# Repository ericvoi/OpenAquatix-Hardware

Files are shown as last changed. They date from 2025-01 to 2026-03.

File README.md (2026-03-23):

# License



# OpenAquatix Hardware
PCB files for the open-source underwater acoustic modem: OpenAquatix.

OpenAquatix is an open-source underwater acoustic modem that provides a flexible and performative interface for research applications and small-scale hobby projects. Key hardware features include:

1. USB 2.0 interface at 480Mbps
2. In-built power consumption monitoring
3. Ambient pressure and temperature sensing
4. Low-noise analog front-end
5. 6th order bandpass filter on input signals
6. Primary processor is an STM32H723 (512 kB flash and RAM) running at 480 MHz for onboard processing of messages
7. Output power of 30W continuous, 60W peak.
8. Reverse polarity and surge protection
9. Standby power consumption of 2 mW
10. Listening power consumption of 100 mW
11. Active processing power consumption of 1 W
12. Fully customizable daughter card for limitless AUV/User - Modem communication protocols (Ethernet, RS232, RS485, CAN, Modbus, etc.)
13. Cost of each board (transducer excluded) fully assembled at quantities of 5+: $110 USD
14. Input feedback network to test novel modulation/demodulation techniques on real hardware
15. Output feedback network to calibrate phase non-linearities in the output chain
16. 2 MB external flash
17. SWD debugging interface

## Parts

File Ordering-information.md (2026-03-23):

_The information in this guide applies to board version(s) v2 only_

# Ordering Boards From JLCPCB

 The production info for these boards has only been generated for JLCPCB. Using another manufacturer will require you to generate their required production information.

## Option 1: Ordering Assembled Boards from JLCPCB

1. Create an account on <https://jlcpcb.com> if you do not have one already
1. Go to <https://jlcpcb.com/parts> and upload the bom file found in `v2/src/production/OpenAquatix_v2_bom.csv` to the Bom tool. 
2. Select the quantity required and click "Process BOM"
3. Verify that the matched part count aligns with the expected value (129 for v2 TODO CHANGE ME) for the board. In case of discrepancies, please open an issue
4. Click on "Add All to My parts lib"
5. Go to <https://jlcpcb.com/user-center/smtPrivateLibrary/partsCart> and verify that the number of parts in the cart aligns with the number ordered in previous steps. In case of any discrepancies, first try to scroll down in the cart, but if only 100 parts get loaded, try switching browsers. Edge and Chrome have been observed to only load 100 parts in the cart while there have been no issues with Firefox. Once confirmed, checkout.
6. Some of the parts ordered in the previous step are "pre-ordered" meaning that they are not currently in-stock, but JLCPCB will attempt to source them from their suppliers. Typical lead times for these components are ~5-15 business days. If they cannot source a component, then they will notify you and you can either source the component from another supplier (Digikey, Mouser, etc.) and solder it yourself or send them the component (consign it). The latter option is not recommended as there are egregious shipping fees and delays. You can also try to substitute the component. JLCPCB will give you a quote ~2 days after the order is placed where you can either decide that the quoted price/shipping time is adequate or that it is too long and cancel the item.
7. Once all of the items have arrived in the JLCPCB parts library, you can begin the actual order for the assembled boards by uploading`v2/src/production/OpenAquatix_v2.zip` to <https://cart.jlcpcb.com/quote>.
8. Update the PCB order specifications as follows:
    1. `PCB Qty` -> The minimum multiple of 5 greater than the number of boards you need. E.g. 6 boards -> qty: 10.
    1. `Material Type` -> `FR4 TG155`
    2. `Specify Stackup` -> `Yes` and change `No Requirement` to `JLC06161H-3313`
9. Select `PCB Assembly` at the bottom of the page and change the following options:
    1. `PCBA Type` -> `Standard`
    2. `PCBA Qty` -> The number of boards you want to order
    3. (Optional) `Confirm Parts Placement` -> `Yes`. For advanced users only who could reasonably be able to detect any flaws with production files (unlikely but recommended for larger orders)
    4. `Bake Components` -> `Yes` and request that C2843785 is baked. This is the WS2812B LED
    5. (Optional, adds 1 day, but is cheap) `Depanel boards & edge rail before delivery` -> `Yes`
10. Click on `Next` on the right side column to get to the assembly details
11. Upload the BOM and positions files on the next screen
12. Place the board order

## Option 2: Assembling Boards Yourself

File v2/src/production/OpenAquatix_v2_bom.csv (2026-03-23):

Designator | Footprint | Quantity | Value | LCSC Part #
C1, C10, C104, C106, C107, C108, C11, C110, C112, C113, C114, C115, C116, C117, C128, C129, C130, C131, C133, C134, C14, C140, C141, C143, C144, C145, C146, C147, C18, C19, C29, C38, C4, C40, C41, C42, C53, C54, C57, C58, C6, C61, C65, C68, C7, C71, C77, C79, C8, C80, C9, C91 | 0603 | 52 | 100n | C14663
C100, C101 | 0603 | 2 | 1n,50V | C309468
C102, C103 | 0603 | 2 | 10n,50V | C57112
C105, C142, C2, C20, C24, C33, C63, C81, C85, C86, C87 | 0603 | 11 | 1u | C15849
C109, C132, C135, C136, C137, C138, C139, C36, C69, C94, C95 | 0603 | 11 | 1n | C309468
C111 | 0603 | 1 | 10u | C2959727
C119, C89, C90, C92, C93 | 0603 | 5 | 33n | C576851
C12, C17 | 0603 | 2 | 8p | C36508
C120, C43 | 0805 | 2 | 10u | C15850
C121, C30, C83 | 0603 | 3 | 10n | C57112
C122, C3, C5, C66, C67 | 0603 | 5 | 2u2 | C23630
C123 | 2220 | 1 | 68n,200V,5%,C0G/NP0 | C2175506
C13, C16 | 0603 | 2 | 47p | C1671
C15, C39 | 0603 | 2 | 4u7 | C19666
C21, C22, C26 | 1210 | 3 | 10u,50V | C77102
C23 | 0603 | 1 | 330n | C1615
C25, C31, C32 | 0805 | 3 | 2u2 | C377773
C27, C55, C56 | 1210 | 3 | 4u7,50V | C86052
C28 | 0603 | 1 | 68p | C62782
C34 | 1210 | 1 | 47u | C77101
C35, C37, C44 | 1210 | 3 | 22u | C309062
C45, C46, C47 | 1210 | 3 | 10u,63V | C437568
C48, C50, C51, C52 | 0805 | 4 | 22u | C45783
C49 | 0805 | 1 | 1u,100V | C105952
C59, C60 | 1210 | 2 | 22u,25V | C309062
C62, C64 | 0603 | 2 | 30p | C1658
C70 | 0603 | 1 | 1n2 | C576796
C72 | 0603 | 1 | 100p | C14858
C73 | 0603 | 1 | 6n8 | C1631
C74, C76, C82, C84 | 0805 | 4 | 1u | C105952
C75 | 1210 | 1 | 10u | C77102
C96, C97 | 1206 | 2 | 680n,100V | C710483
C98, C99 | 0805 | 2 | 220n,100V | C513710
D1 | LED_WS2812B_PLCC4_5.0x5.0mm_P3.2mm | 1 | WS2812B | C2843785
D10 | SC-59 | 1 | 1SS396,LF | C2762668
D11 | D_SOD-323F | 1 | BAT54WS | C22629
D2 | TO-277B | 1 | PDS760-13 | C3018534
D3 | SMBJ | 1 | SMBJ24CA | C83268
D4 | SOD-123_ONS | 1 | MMSZ12T1G | C72599
D5, D6, D7, D8 | 0603 | 4 | Red | C2286
D9 | D_SMC | 1 | SMLJ150CA | C5924268
F1 | 1206 | 1 | 6A | C3165603
J1 | PinHeader_2x05_P1.27mm_Vertical | 1 | Conn_ARM_JTAG_SWD_10 | C5883263
J2, J3 | USB_Micro-B_Amphenol_10118193-0001LF_Horizontal | 2 | USB_B_Micro | C132562
J4 | UAM_DaughterCard | 1 | ~
J5 | CONN2_2601-1102_WAG | 1 | 2601-1102 | C7509568
J6 | CONN3_2601-1103_WAG | 1 | 2601-1103 | C7472698
L1 | L_Bourns_SRP6060FA | 1 | 6u8 | C2047089
L2 | L_Bourns_SRP6060FA | 1 | 15u | C2047415
L3 | L_Bourns-SRN8040_8x8.15mm | 1 | 33u | C780189
L4, L5 | CDRH127L125NP | 2 | 33u | C2595984
L6 | B82477D4xxxM900 | 1 | 136u | C1016922
L7, L9 | L_Pulse_PA4344 | 2 | 100u | C2452965
Q1, Q10, Q12, Q13, Q4, Q5, Q6, Q7, Q8, Q9 | SOT-23 | 10 | BSS138 | C40912
Q11 | SOT-23 | 1 | DMP3068L-7 | C151010
Q2 | VSON-8_3.3x3.3mm_P0.65mm_NexFET | 1 | CSD18543Q3A | C840100
Q3 | Vishay_PowerPAK_1212-8_Single | 1 | Si7617DN | C727607
R10, R11, R36, R85 | 0603 | 4 | 2k49 | C100897
R100, R13 | 0603 | 2 | 56k | C23206
R101 | 0603 | 1 | 8k66 | C23114
R102 | 0603 | 1 | 2k05 | C22900
R103 | 0603 | 1 | 16k9 | C25954
R104, R110, R111, R112, R29, R37, R56, R57, R6, R96 | 0603 | 10 | 10k | C25804
R105 | 0603 | 1 | 1k91 | C22853
R106 | 0603 | 1 | 28k | C22989
R107 | 0603 | 1 | 6k19 | C25978
R108 | 0603 | 1 | 1k18 | C858885
R109 | 0603 | 1 | 17k4 | C22819
R113, R115, R116, R18, R20, R26, R50, R53, R70, R73, R76, R79, R83, R89, R92 | 0603 | 15 | 100k | C25803
R114, R14, R40, R41, R46, R47, R97 | 0603 | 7 | 390R | C23151
R12 | 0603 | 1 | 33k | C4216
R15, R19, R21, R71, R74, R84 | 0603 | 6 | 2k | C22975
R16, R17, R48, R7, R88, R9 | 0603 | 6 | 22R | C23345
R22, R23, R43 | 0603 | 3 | 4k7 | C23162
R24 | 0603 | 1 | 28k7 | C100933
R25, R8, R90, R91, R93, R99 | 0603 | 6 | 1k | C21190
R27 | 0603 | 1 | 150k | C22807
R28 | 0603 | 1 | 21k | C22956
R30 | 0603 | 1 | 267R | C22924
R31 | 0603 | 1 | 68k | C23231
R32 | 0603 | 1 | 39k | C23153
R33, R67, R68 | 0603 | 3 | 100R | C22775
R34, R66 | 0805 | 2 | 10m | C104574
R35 | 0603 | 1 | 71k5 | C23103
R38 | 0603 | 1 | 300k | C23024
R39, R62 | 0603 | 2 | 22k | C31850
R4 | 0603 | 1 | 47R | C23182
R42 | 0603 | 1 | 20k | C4184
R44, R49, R87 | 0603 | 3 | 1M | C22935
R45 | 0603 | 1 | 8k06 | C23112
R51, R54 | 0603 | 2 | 470R | C23179
R52 | 0603 | 1 | 499R | C23065
R55 | 0603 | 1 | 2k94 | C22909
R58 | 0603 | 1 | 806R | C23116
R59 | 0603 | 1 | 1k21 | C22835
R60, R61, R64, R65 | 0603 | 4 | 3R3 | C22979
R63 | 0603 | 1 | 30k,1% | C22984
R69, R72, R75, R78 | 0603 | 4 | 220R | C22962
R77, R80 | 0603 | 2 | 47k | C25819
R81 | 1206 | 1 | 160k,1% | C4437
R82 | 0603 | 1 | 1k6,1% | C22847
R86 | 0603 | 1 | 732R | C23106
R94 | 0603 | 1 | 200R | C8218
R95 | 0603 | 1 | 91k | C23265
R98 | 0603 | 1 | 86k6 | C23121
TP1, TP2 | TestPoint_Pad_D1.0mm | 2 | TestPoint
U1 | SOIC-8_5.3x5.3mm_P1.27mm | 1 | W25Q16JVSS | C82317
U10 | SOT-23-5 | 1 | TPS60403DBV | C11338
U11 | WSON-12-1EP_3x2mm_P0.5mm_EP1x2.65 | 1 | LM5155DSSR | C545416
U12 | SOT-23-5 | 1 | TPS72301DBV | C34678
U13, U14 | WSON-6-1EP_2x2mm_P0.65mm_EP1x1.6mm | 2 | TLV75733PDRVR | C2868428
U15 | SOT-23-6 | 1 | LMR54406 | C5219316
U16, U18, U4, U5 | USON-10_2.5x1.0mm_P0.5mm | 4 | TPD4E05U06DQA | C138714
U17 | QFN-24-1EP_4x4mm_P0.5mm_EP2.6x2.6mm | 1 | USB3343 | C112967
U19 | MSOP-10_3x3mm_P0.5mm | 1 | OPA2316 | C2060790
U2 | LQFP-100_14x14mm_P0.5mm | 1 | STM32H723VET6 | C730141
U20 | HTSSOP-44-1EP_6.1x14mm_P0.635mm_EP5.2x14mm_Mask4.31x8.26mm | 1 | TPA3244DDWR | C544669
U21 | ST_HLGA-10_2x2mm_P0.5mm_LayoutBorder3x2y | 1 | LPS22HH | C2827824
U22 | SOT-23-8 | 1 | INA219AIDCNR | C87469
U23, U25 | SOT-23-6 | 2 | OPA991SIDBVR | C2864547
U24, U3, U34 | SOT-363_SC-70-6 | 3 | TS5A4624 | C485533
U26 | SOT-23-5 | 1 | LM6211 | C2060609
U27, U28, U29, U30, U31, U32 | SOT-23-5 | 6 | LMV641MFX/NOPB | C2059681
U33 | TSSOP-10_3x3mm_P0.5mm | 1 | PGA113 | C2057394
U35 | RELAY_AQY_SO4_KS_PAN | 1 | AQY210S | C132163
U6, U7 | SOT-363_SC-70-6 | 2 | TPS22919 | C2149796
U8 | HTSOP-8-1EP_3.9x4.9mm_P1.27mm_EP2.4x3.2mm | 1 | BV1HB045EFJ-C | C17309972
U9 | LMR66430R5RXBR | 1 | LMQ66430R5RXBR | C22440565
Y1 | Crystal_SMD_3225-4Pin_3.2x2.5mm | 1 | 32.768 kHz | C213398
Y2 | Crystal_SMD_5032-4Pin_5.0x3.2mm | 1 | 8 MHz | C5154132
Y3 | Crystal_SMD_3225-4Pin_3.2x2.5mm | 1 | 26 MHz | C5143383

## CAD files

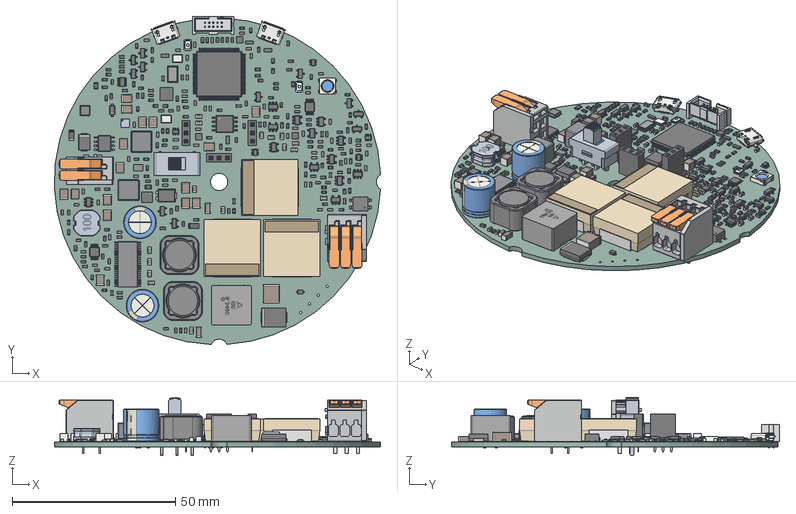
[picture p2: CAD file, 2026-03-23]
v2/src/3d_board/UAM.step
99.9 x 100.4 x 17.9 mm
SOT-23-5 x 9
SHF-105-01-D_header
SHF-First_Position_Indicator
T-1S71-02-05-D-TH
R_0603_1608Metric x 113
USON-10_2.5x1.0mm_P0.5mm x 4
C_0603_1608Metric x 106
C_0805_2012Metric x 16
L_Bourns_SRP6060FA x 2
C_1210_3225Metric x 16
SOT-23 x 11
Crystal_SMD_3225-4Pin_3.2x2.5mm x 2
ST_HLGA-10_2x2mm_P0.5mm_LayoutBorder3x2y
SC-59
SI7617DN-T1-GE3
R_0805_2012Metric x 2
D_SOD-123
USB_Micro-B_Molex_47346-0001 x 2
D_0603_1608Metric x 4
IND_44_104NLT_PUL x 3
SOT-23-8
EVP-AWED4A x 2
SOT-363_SC-70-6 x 5
CDRH127L125NP-330MC x 2
LED_WS2812B_PLCC4_5.0x5.0mm_P3.2mm
BODY-SO
LEAD-SO x 44
THERMALPAD-SO
PIN1-ID x 2
TO-277B
CP_Radial_D10.0mm_P5.00mm x 2
D_SMC
SOIC-8_5.3x5.3mm_P1.27mm
WSON-6-1EP_2x2mm_P0.65mm_EP1x1.6mm x 2
PinSocket_1x03_P2.54mm_Vertical x 3
PAN_AQY21-SO4_PAN
C_1206_3216Metric x 2
C_2220_5750Metric
SOT-23-6 x 3
D_SOD-323F
QFN-24-1EP_4x4mm_P0.5mm_EP2.6x2.6mm
LQFP-100_14x14mm_P0.5mm
VSON-8_3.3x3.3mm_P0.65mm_NexFET
R_1206_3216Metric
D_SMB
b82477d4_m900
HTSOP-8-1EP_3.9x4.9mm_P1.27mm_EP2.4x3.2mm
srn8040
BODY-SON
MSOP-10_3x3mm_P0.5mm
TSSOP-10_3x3mm_P0.5mm
UAM 1.307
CS12ANW03-body
CS12ANW03-top
CS12ANW03-term
CS12ANW03-slide
Crystal_SMD_5032-2Pin_5.0x3.2mm
Fuse_1206_3216Metric
OpenAquatix-Hardware_PCB

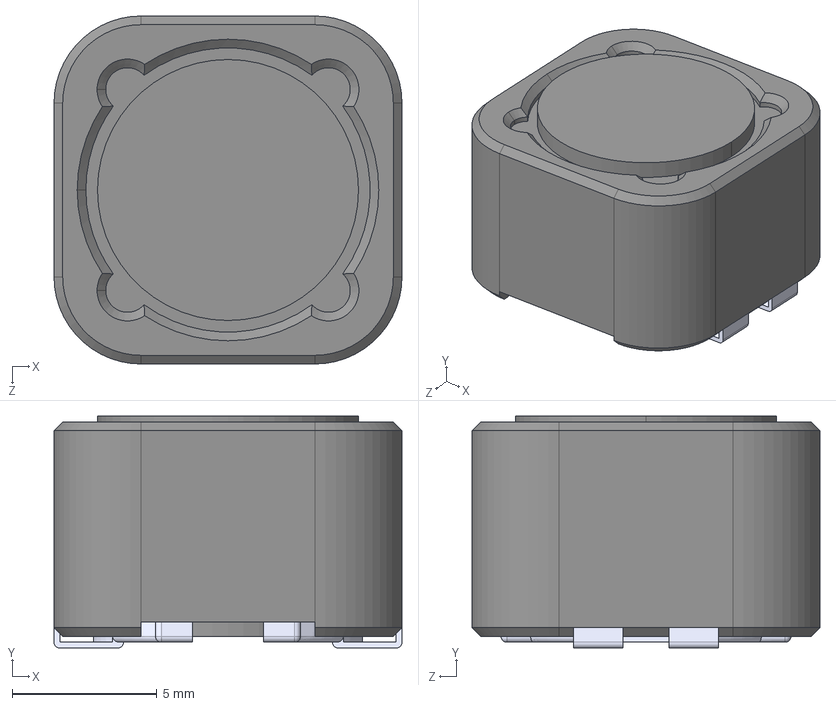
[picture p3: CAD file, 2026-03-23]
v2/src/3d_models/CDRH127L125NP-330MC.STEP
12.0 x 8.00 x 12.0 mm

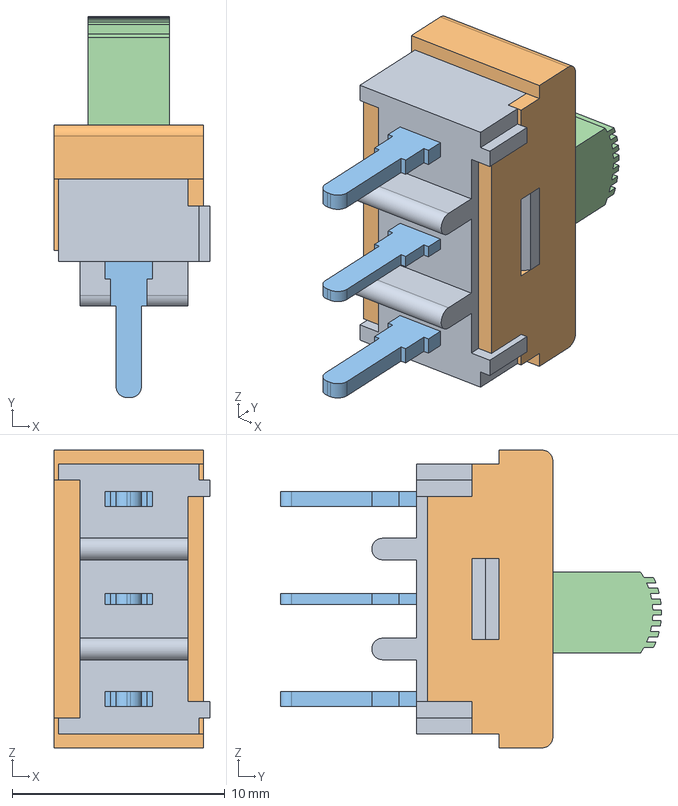
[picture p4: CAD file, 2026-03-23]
v2/src/3d_models/CS12ANW03.stp
7.32 x 17.9 x 14.0 mm
CS12ANW03-body
CS12ANW03-top
CS12ANW03-term
CS12ANW03-slide

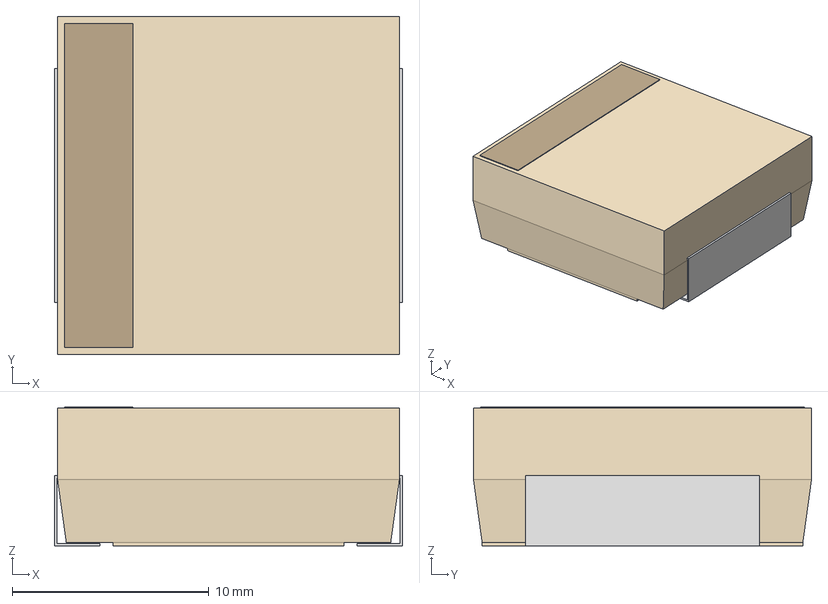
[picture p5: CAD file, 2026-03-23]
v2/src/3d_models/IND_44_104NLT_PUL.step
17.7 x 17.2 x 7.06 mm

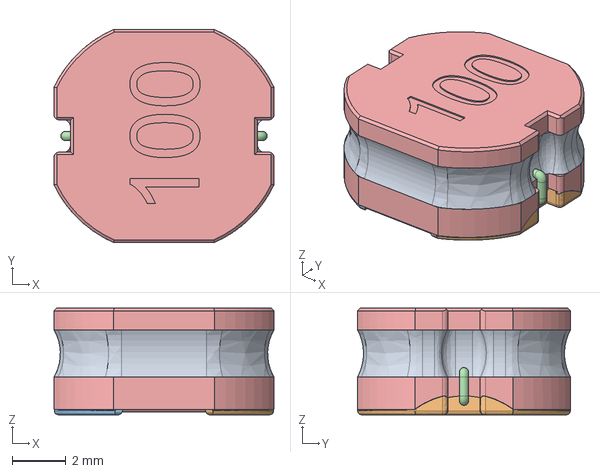
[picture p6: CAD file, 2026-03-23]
v2/src/3d_models/srn8040.stp
8.15 x 7.90 x 3.95 mm

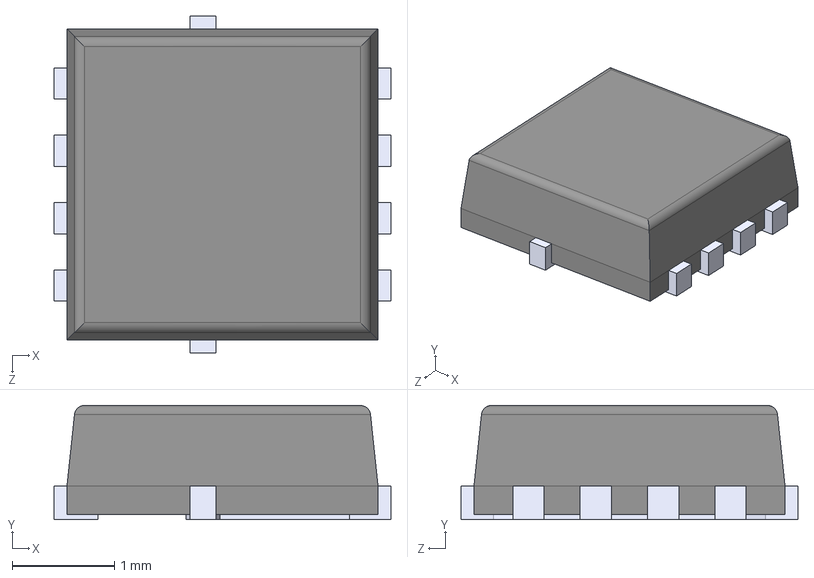
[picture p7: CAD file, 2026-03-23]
v2/src/3d_models/SI7617DN-T1-GE3.STEP
3.30 x 1.12 x 3.30 mm

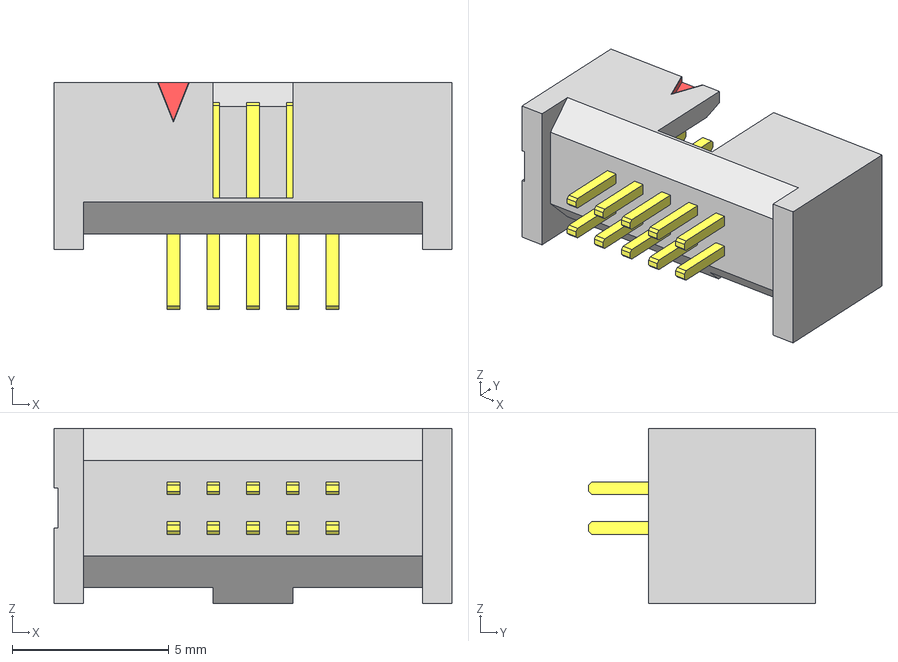
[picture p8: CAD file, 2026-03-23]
v2/src/3d_models/SHF-105-01-L-D-TH.stp
12.7 x 7.24 x 5.59 mm
SHF-105-01-D_header
SHF-First_Position_Indicator
T-1S71-02-05-D-TH

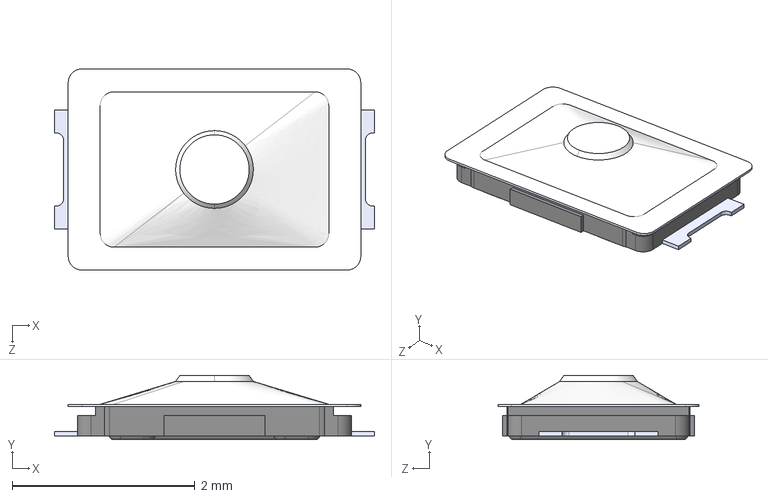
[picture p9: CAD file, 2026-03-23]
v2/src/3d_models/EVP-AWED4A.STEP
3.50 x 0.7 x 2.20 mm

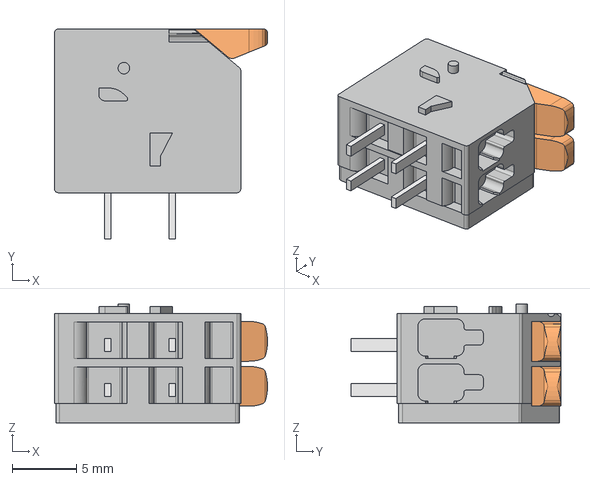
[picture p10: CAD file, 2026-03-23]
v2/src/3d_models/2601-1102.stp
16.6 x 16.4 x 9.25 mm

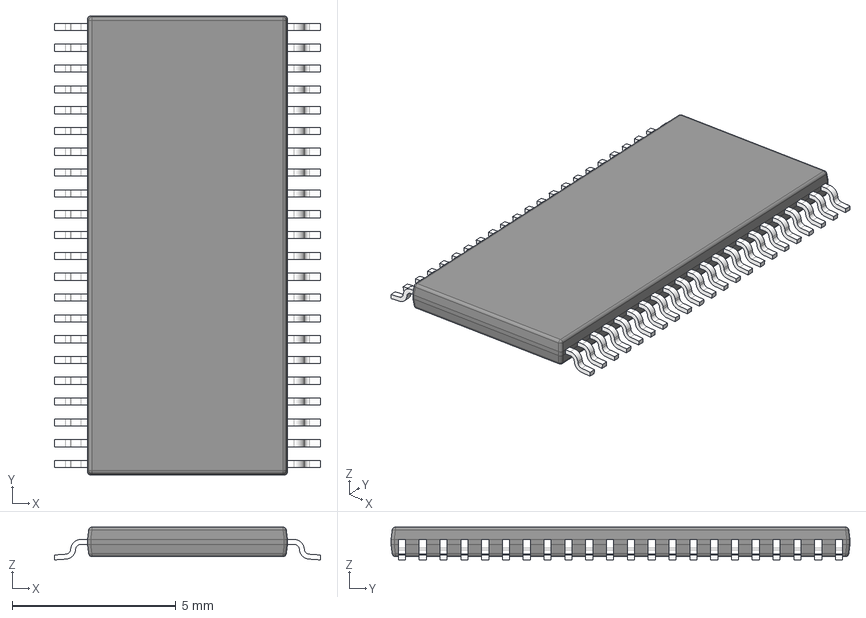
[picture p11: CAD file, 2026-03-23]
v2/src/3d_models/DDW0044D.stp
8.12 x 14.0 x 1.00 mm
BODY-SO
LEAD-SO x 44
THERMALPAD-SO
PIN1-ID

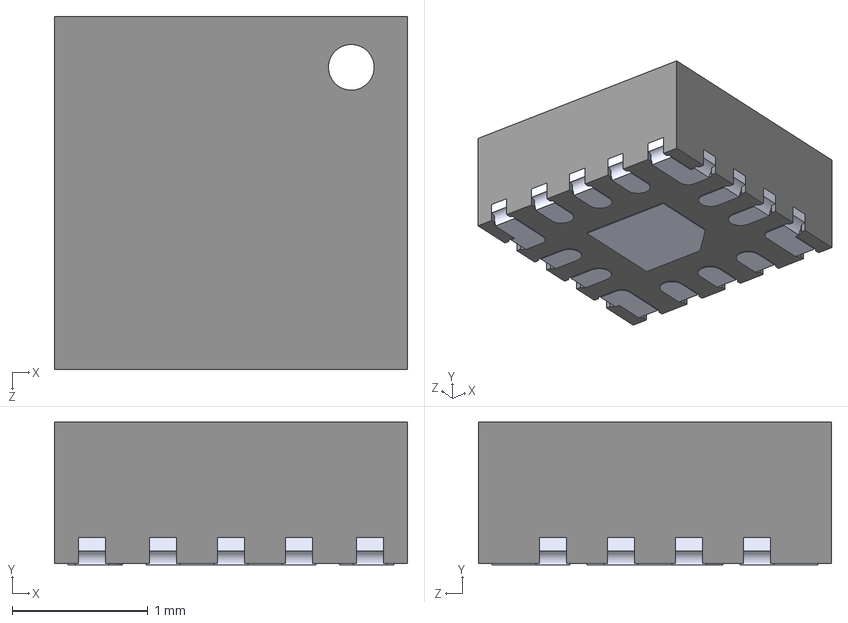
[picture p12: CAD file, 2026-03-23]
v2/src/3d_models/14-VQFN.STEP
2.60 x 1.05 x 2.60 mm

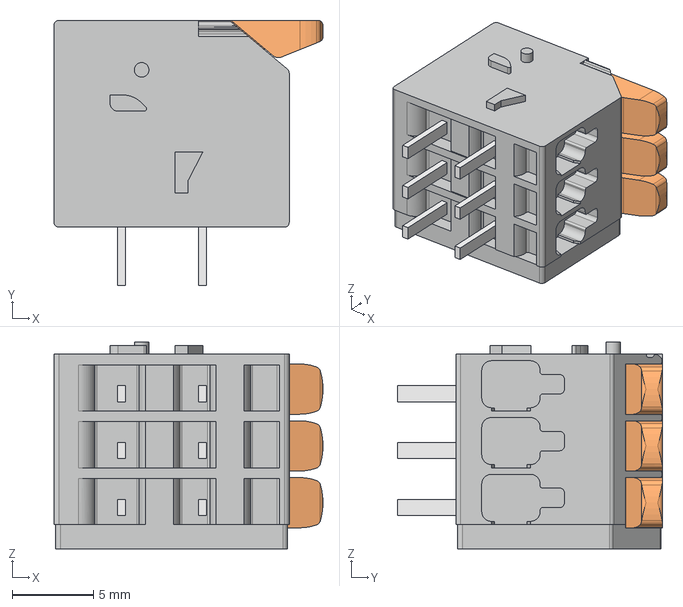
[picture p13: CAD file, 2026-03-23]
v2/src/3d_models/2601-1103.stp
16.6 x 16.4 x 12.8 mm

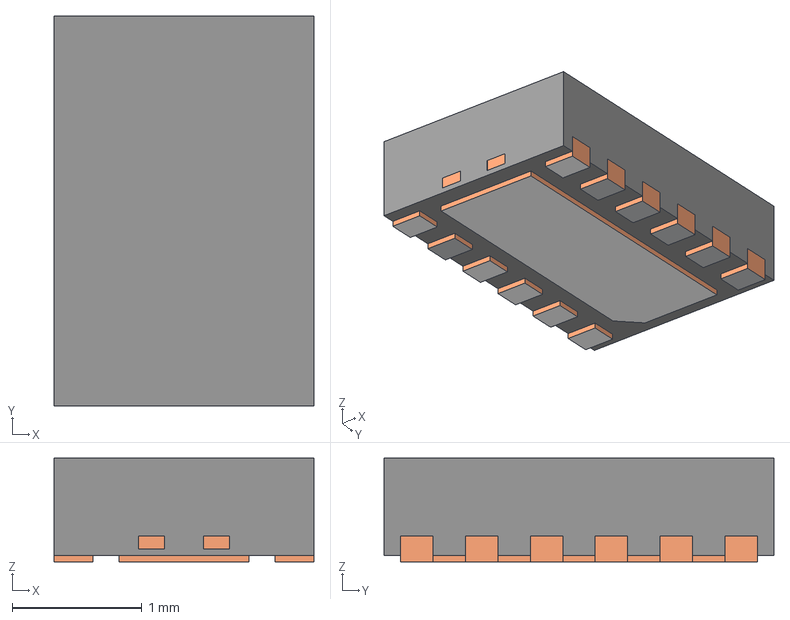
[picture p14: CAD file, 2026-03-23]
v2/src/3d_models/DSS0012B.stp
2.00 x 3.00 x 0.8 mm
BODY-SON
FRAME-DSS0012B
PIN1-ID

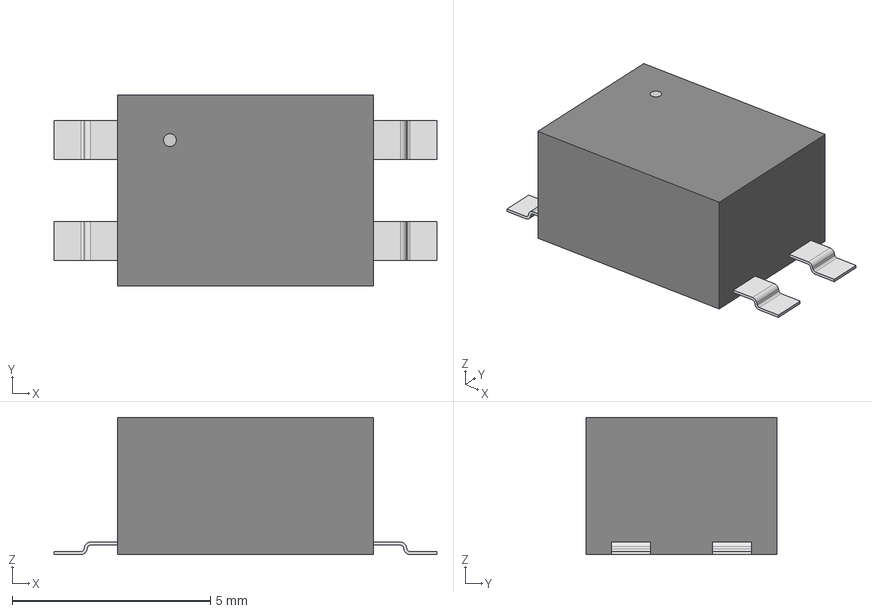
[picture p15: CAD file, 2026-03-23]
v2/src/3d_models/PAN_AQY21-SO4_PAN.step
9.65 x 4.83 x 3.46 mm

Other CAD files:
v2/src/3d_models/10118193-0001lfc.step
v2/src/3d_models/b82477d4_m900.step

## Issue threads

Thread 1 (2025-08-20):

Decrease Power Consumption

CJcockrall, 2025-08-20:
This is a large, overarching issue. Power consumption should be lowered dramatically and should be considered in every component of the modem. Try to track improvements made to power consumption in this issue.

**Target power consumption in shutdown mode: 10 mW**
**Target power consumption in light sleep (can be woken up by acoustic signal): <75 mW to 150 mW**

Some specific misc. places to consider power consumption:
- pullup/pulldown resistors
- quiescent currents when ICs disabled
- leakage currents
- efficiency of DC-DC converters at different output current levels (efficiency currently 50% at low currents)

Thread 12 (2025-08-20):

Change Reverse Polarity Protection

CJcockrall, 2025-08-20:
Use MOSFET instead. See: https://www.reddit.com/r/AskElectronics/comments/1722e6e/comment/k3v5e08/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

CJcockrall, 2025-09-01:
Narrowed down to two P-channel MOSFETS to pick from. Examine tradeoffs based on table.

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

CJcockrall, 2025-09-02:
Settled on the GSFD6959 for cheaper cost and similar performance.
https://goodarksemi.com/docs/datasheets/mosfets/GSFD6959.pdf

Closed 2025-09-02.

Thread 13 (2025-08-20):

New fuse

CJcockrall, 2025-08-20:
Implement new fuse for the new board version. Should probably be done near the end.

Choose a medium or slow blow fuse. Try to calculate the I2t time required and then 2x-3x it to choose a fuse. I2t is the area under the I^2 vs time curve. You can assume a basic resistor-capacitor charging circuit with downstream capacitors on different power rails appropriately considered (hint: The important parameter is charge in the capacitor which scales with voltage and capacitance).

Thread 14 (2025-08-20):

MOSFETS for cutting off power to components.

CJcockrall, 2025-08-20:
When cutting off power to components, use p- or n- mosfets depending on whether high side or low side switching is required respectively. If using high side switching, an additional mosfet will be required to protect the uC. As such, prefer low-side switching when possible, but for ICs, it is often preferable to keep the ground connection and sever the power connection. Consider leakage currents for power consumption!!!

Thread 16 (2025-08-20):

Prevent both pins being on at the same time

CJcockrall, 2025-08-20:
No more single GPIO pin for the SSR since both need to be off for low power but to prevent both being on at the same time (firmware fault), prevent this somehow in hardware

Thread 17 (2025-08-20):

Change 5V selection method

CJcockrall, 2025-08-20:
There should not be any leakage which was caused by MOSFET's body diode.

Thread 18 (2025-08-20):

Implement higher accuracy oscillator.

CJcockrall, 2025-08-20:
Needs to be used during sleep mode, and higher accuracy means higher power consumption. The current oscillator is ~100ppm worst case. Only replace the crystal if 20-30 ppm can be achieved at least. The crystal/oscillator can be turned off in low power modes.

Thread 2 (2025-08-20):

Change Power Amplifier

CJcockrall, 2025-08-20:
Current power amplifier (TPA3132D2) has poor bandwidth. A new power amplifier should have larger bandwidth and ideally a lower baseline current draw (currently it is around ~40 mA, maybe)

CJcockrall, 2025-08-25:
[TPA3244](https://www.ti.com/lit/ds/symlink/tpa3244.pdf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) is a good contender:

Positives:
- High bandwidth (100kHz compared to current ~40kHz)
- High max power output (60W per channel at 8 ohm load compared to ~25W or so)
- Good power efficiency (94% compared to >90%)

Negatives:
- Much larger package size (HTSSOP-44 compared to VQFN-32)
- Needs additional 12V rail
- Not necessarily an improvement on idle power draw, but not significantly more.
- More expensive ($6.08 vs $2.30 on digikey)

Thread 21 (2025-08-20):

Change 5V Buck Converter

CJcockrall, 2025-08-20:
The current buck converter has poor efficiency at low output currents. Calculate the required output current based on the microcontroller requiring 400 mA (overestimate) and then calculating other uses based on a maximum use scenario.

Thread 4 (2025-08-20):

Make PCB(s) click to order

CJcockrall, 2025-08-20:
Making it click to order: use the 'Fabrication tool-kit' [KiCad plugin](https://github.com/bennymeg/Fabrication-Toolkit) and add a field to every component called 'LCSC PN' with the part number as found on [LCSC](https://www.lcsc.com/). In case a component does not have an LCSC PN, just say N/A. If possible, try to choose components with a LCSC PN

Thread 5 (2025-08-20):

Hardware ID Pins for Version Compatibility

CJcockrall, 2025-08-20:
Designate 4 pins for hardware ID. For this board, connect them all to pull-down resistor (4k7) to ground.

These pins will be read at startup to get hardware ID for pin configurations. The GPIO pins will have an internal pull up (~40k), so depending on whether the pull-down resistor is populated, either a 1 or 0 will be read. Future board iterations wont include certain pull-up resistors. Choose 4 pins next to one another with low probability of future use (i.e. duplicate interfaces, or few functions) and far away from critical sections like the analog section (pins 25-49).

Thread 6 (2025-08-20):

Change power and transducer connectors

CJcockrall, 2025-08-20:
These connectors are currently screw terminals that are a hassle to use and have shown signs of wear over time. Change these to screwless (i.e. push button or leg spring style) connectors. Be aware of difficulty with push button connectors.

https://www.digikey.ca/en/products/filter/wire-to-board/371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

CJcockrall, 2025-09-01:
Cost of old connectors is total of $4.53 per board. New, high quality WAGO screwless-lever connectors cost a total of $8.64, but should last much longer and be much easier to use. These connectors also have LCSC PNs.

Transducer Connector: https://www.digikey.ca/en/products/detail/wago-corporation/2601-1102/17122694
Battery Connector: https://www.digikey.ca/en/products/detail/wago-corporation/2601-1103/17121715

Can revise if deemed to be too expensive.

Closed 2025-09-02.

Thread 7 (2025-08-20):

Add External Flash

CJcockrall, 2025-08-20:
For future proofing for future versions. At least 8 Mbit or better. This will use the MCU's flexible memory controller and will require a lot of reading of reference manuals and datasheets.

Consider power consumption, time to program and read memory.

Priority seems lower than some other issues but probably shouldn't be left until last.

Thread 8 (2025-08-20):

Implement Pressure Sensor

CJcockrall, 2025-08-20:
An onboard pressure sensor could be used to detect enclosure leaks. Best one Eric has found is [LPS22HHTR](https://www.digikey.ca/en/products/detail/stmicroelectronics/LPS22HHTR/9586578) as it can measure ~0.1% pressure changes, low power, but it is expensive ($4 CAD - truly an absurd price to Eric). Feature may be marked as DNP.

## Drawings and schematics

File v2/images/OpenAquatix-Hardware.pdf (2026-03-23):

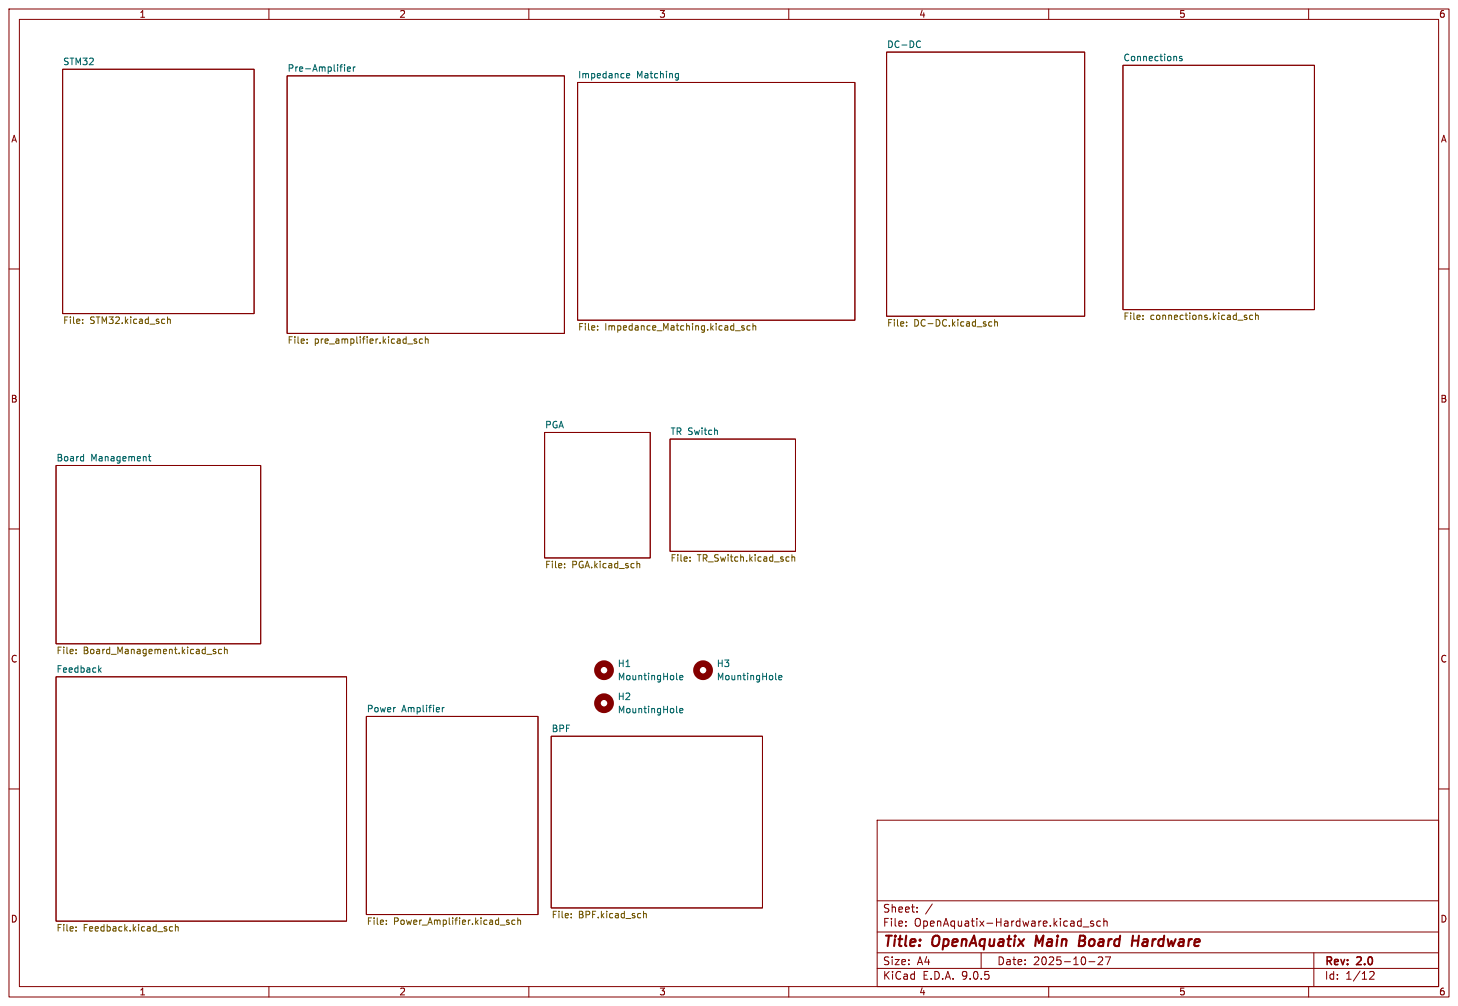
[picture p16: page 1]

File: DC-DC.kicad_sch BPF

File: OpenAquatix-Hardware.kicad_sch Sheet: /
Id: 1/12 Title: OpenAquatix Main Board Hardware

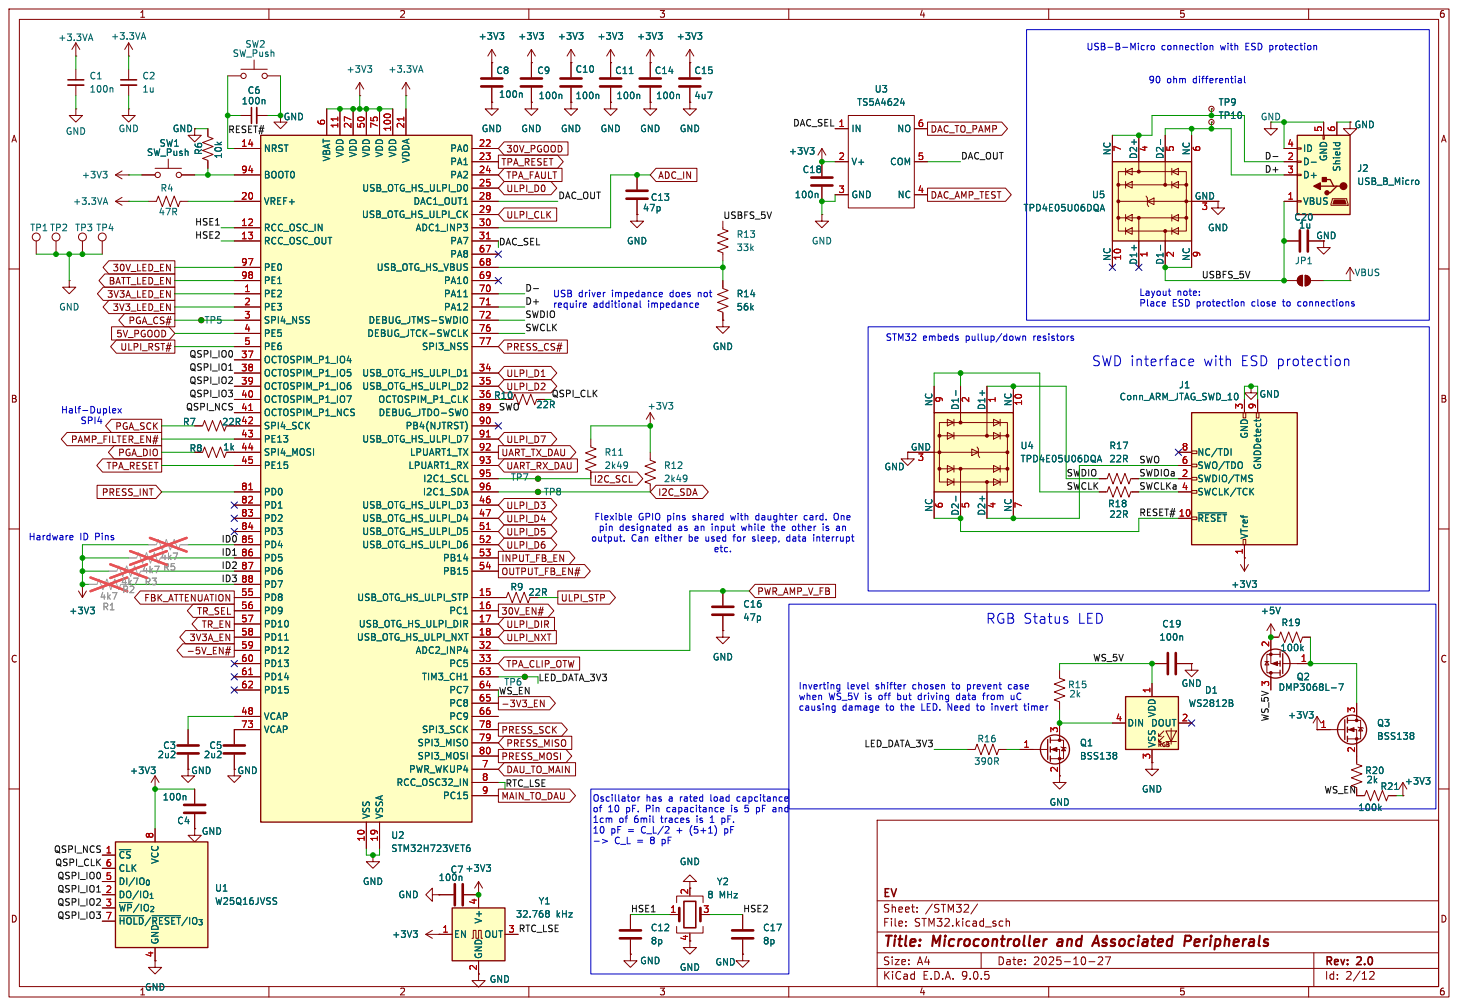
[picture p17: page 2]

6 VDD 11 VDD 27 VDD 50 VSS 10 VDD 75 VSSA 19 VDD 100 VDDA 21 PA0 22 PA1 23 PA2 24 USB_OTG_HS_ULPI_D0 25 DAC1_OUT1 28 USB_OTG_HS_ULPI_CK 29 ADC1_INP3 30 PA7 31 PA8 67 USB_OTG_HS_VBUS 68 PA10 69 PA11 70 PA12 71 DEBUG_JTMS-SWDIO 72 DEBUG_JTCK-SWCLK 76 SPI3_NSS 77 USB_OTG_HS_ULPI_D1 34 USB_OTG_HS_ULPI_D2 35 OCTOSPIM_P1_CLK 36 DEBUG_JTDO-SWO 89 PB4(NJTRST) 90 USB_OTG_HS_ULPI_D7 91

3 ~{RESET} 10 SWCLK/TCK 4 SWDIO/TMS 2 SWO/TDO 6 NC/TDI 8 GND

3 ~{RESET} 10 SWCLK/TCK 4 SWDIO/TMS 2 SWO/TDO 6 NC/TDI 8

2 OUT 3 GND GND GND GND

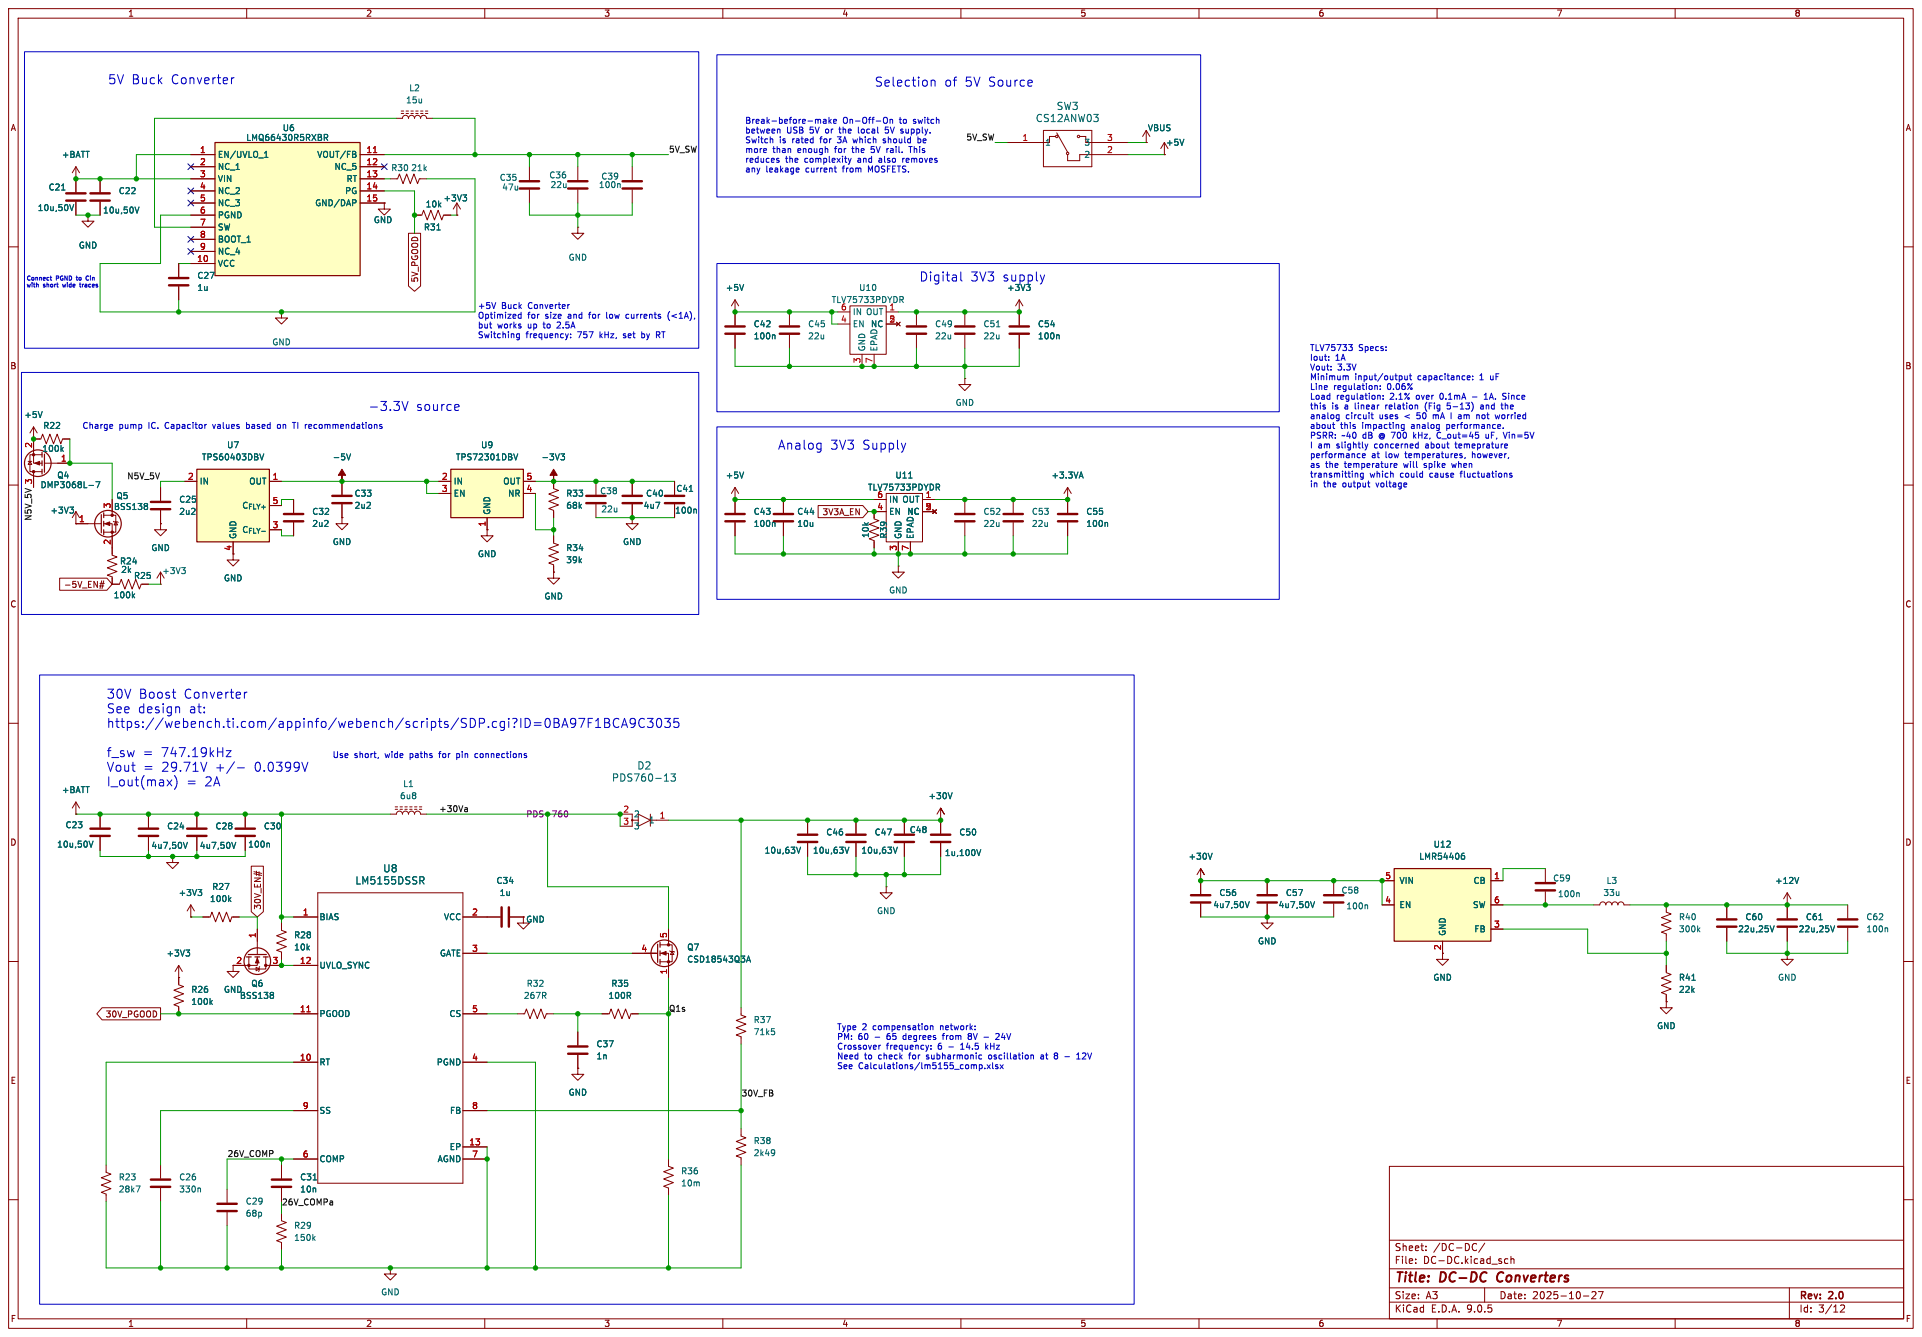
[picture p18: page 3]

between USB 5V or the local 5V supply. Switch is rated for 3A which should be more than enough for the 5V rail. This

Use short, wide paths for pin connections

Id: 3/12 Title: DC-DC Converters

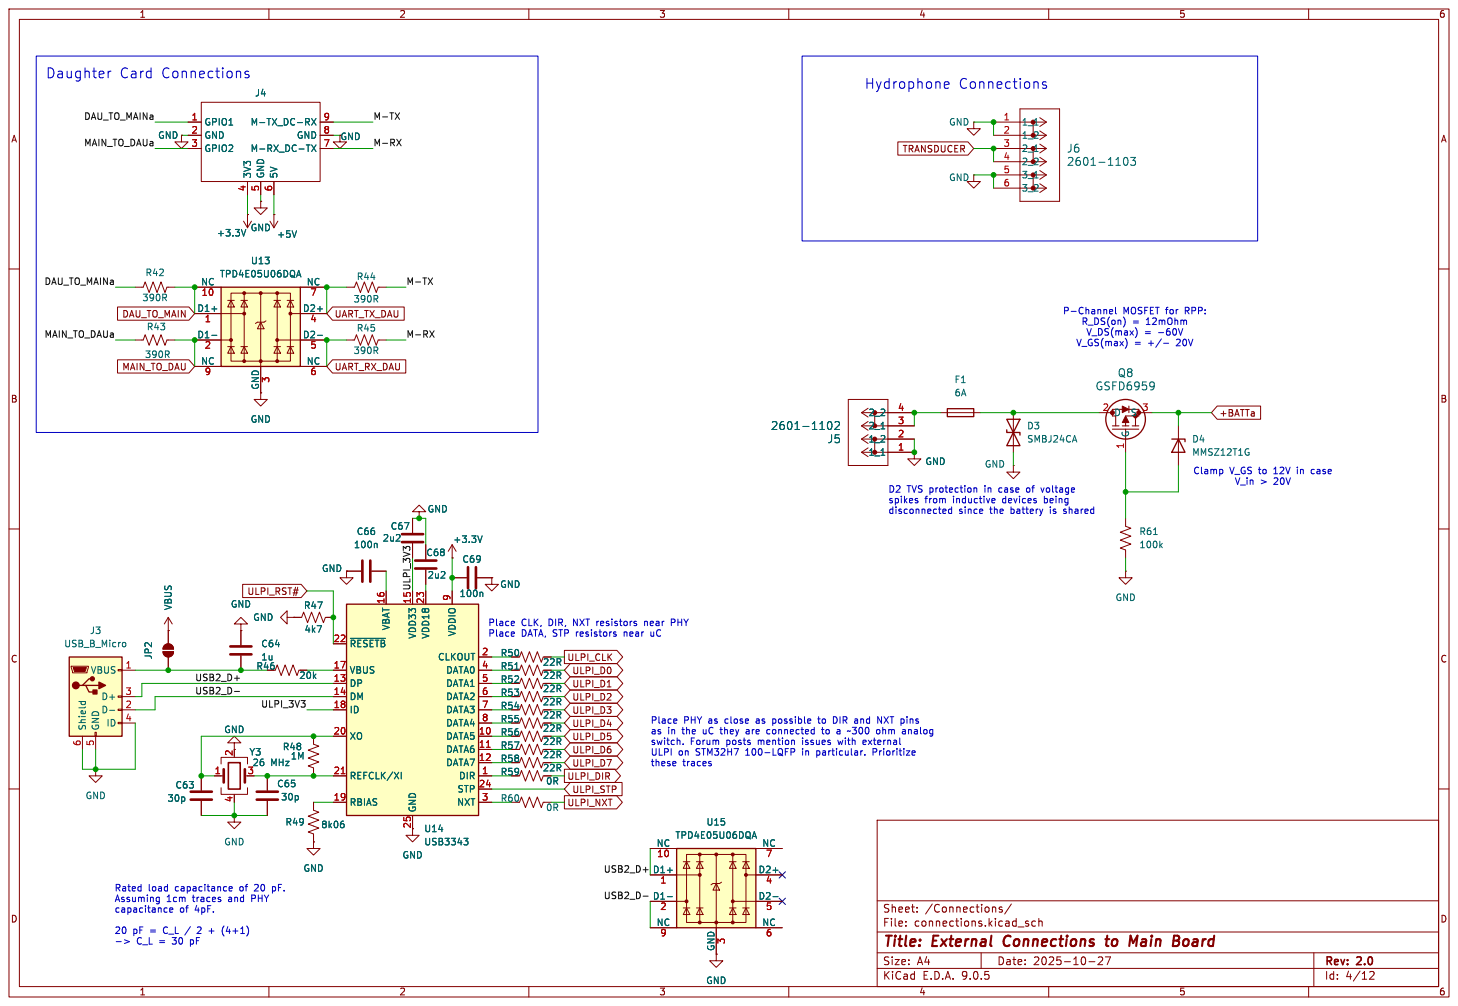
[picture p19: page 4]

6 M-TX_DC-RX 9 GND 8 M-RX_DC-TX 7 GND

9 CLKOUT 2 DATA0 4 DATA1 5 DATA2 6 DATA3 7 DATA4 8 DATA5 10 DATA6 11 DATA7 12 DIR 1 STP 24 NXT 3 U14 USB3343 R49 8k06 R48
20k GND

~{RESETB} 22 VBUS 17 DP 13 DM 14

U14 USB3343 ~{RESETB} 22 VBUS 17 DP 13 DM 14

File: connections.kicad_sch Sheet: /Connections/ C64

Assuming 1cm traces and PHY

Id: 4/12 Title: External Connections to Main Board

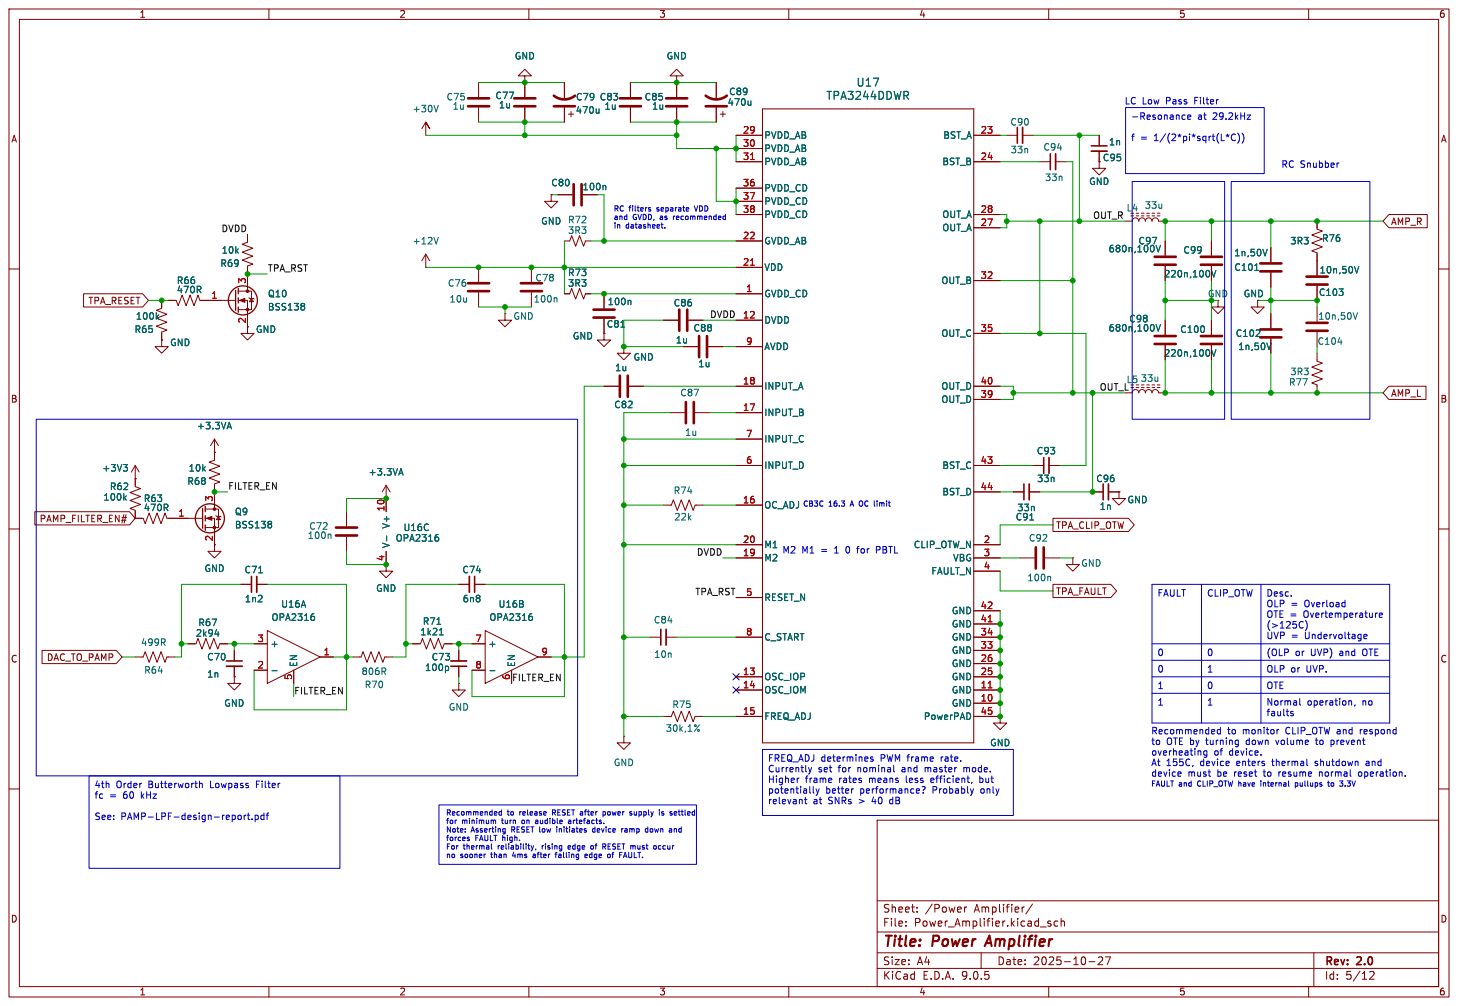
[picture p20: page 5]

and GVDD, as recommended

device must be reset to resume normal operation. R67

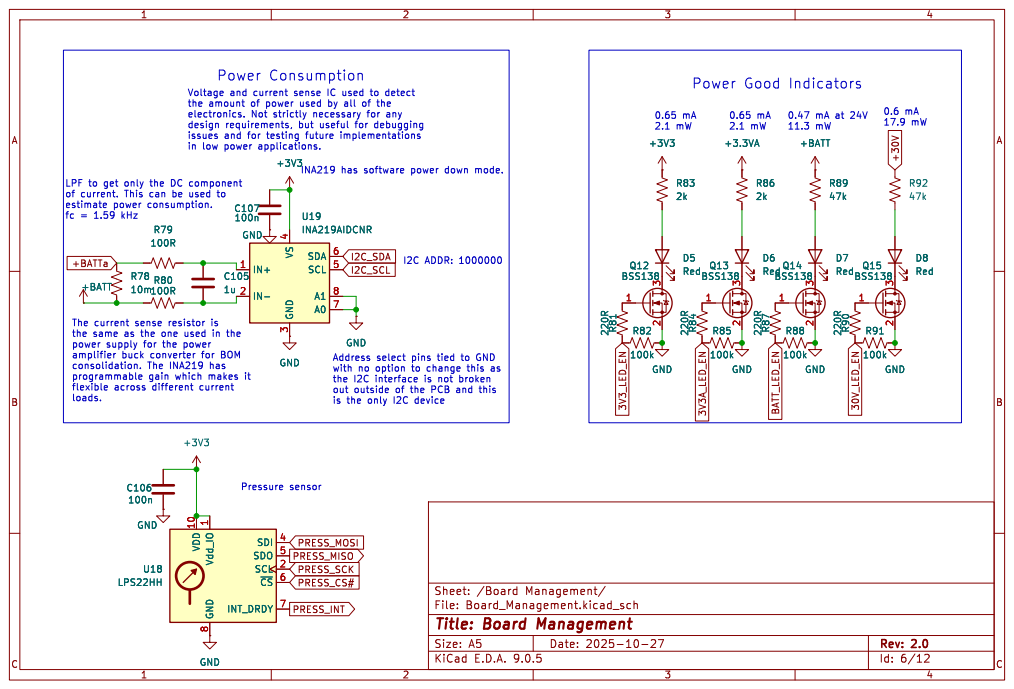
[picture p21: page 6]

Voltage and current sense IC used to detect
the amount of power used by all of the
issues and for testing future implementations
in low power applications.

INA219 has software power down mode.

LPF to get only the DC component
fc = 1.59 kHz

the same as the one used in the
power supply for the power
loads.

with no option to change this as
out outside of the PCB and this
is the only I2C device

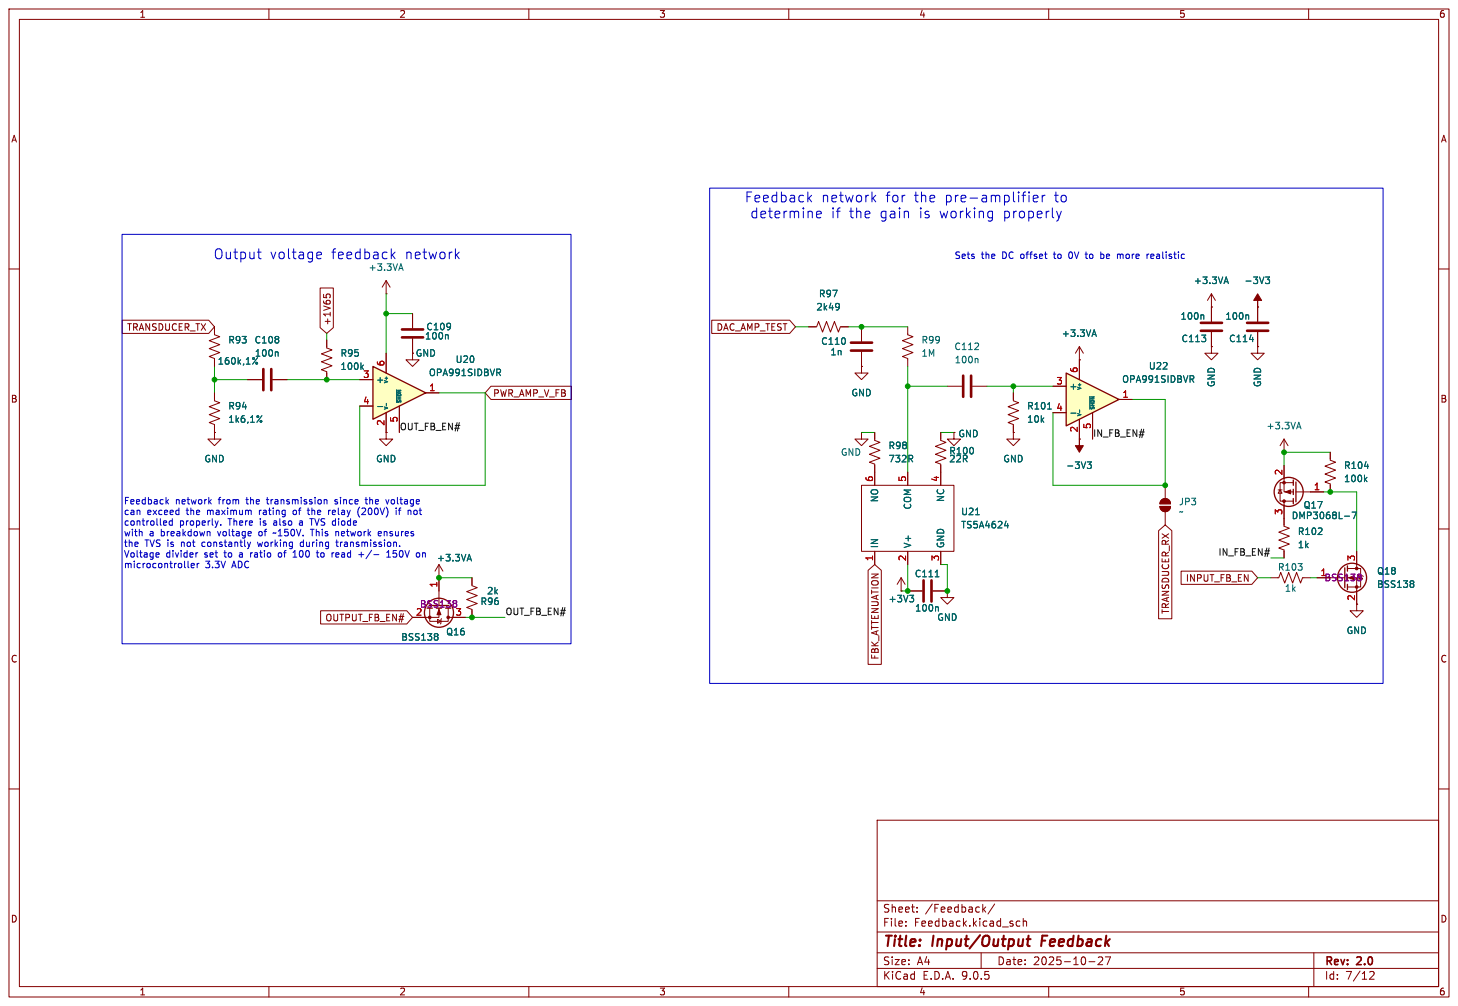
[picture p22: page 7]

Sets the DC offset to 0V to be more realistic GND

File: Feedback.kicad_sch Sheet: /Feedback/

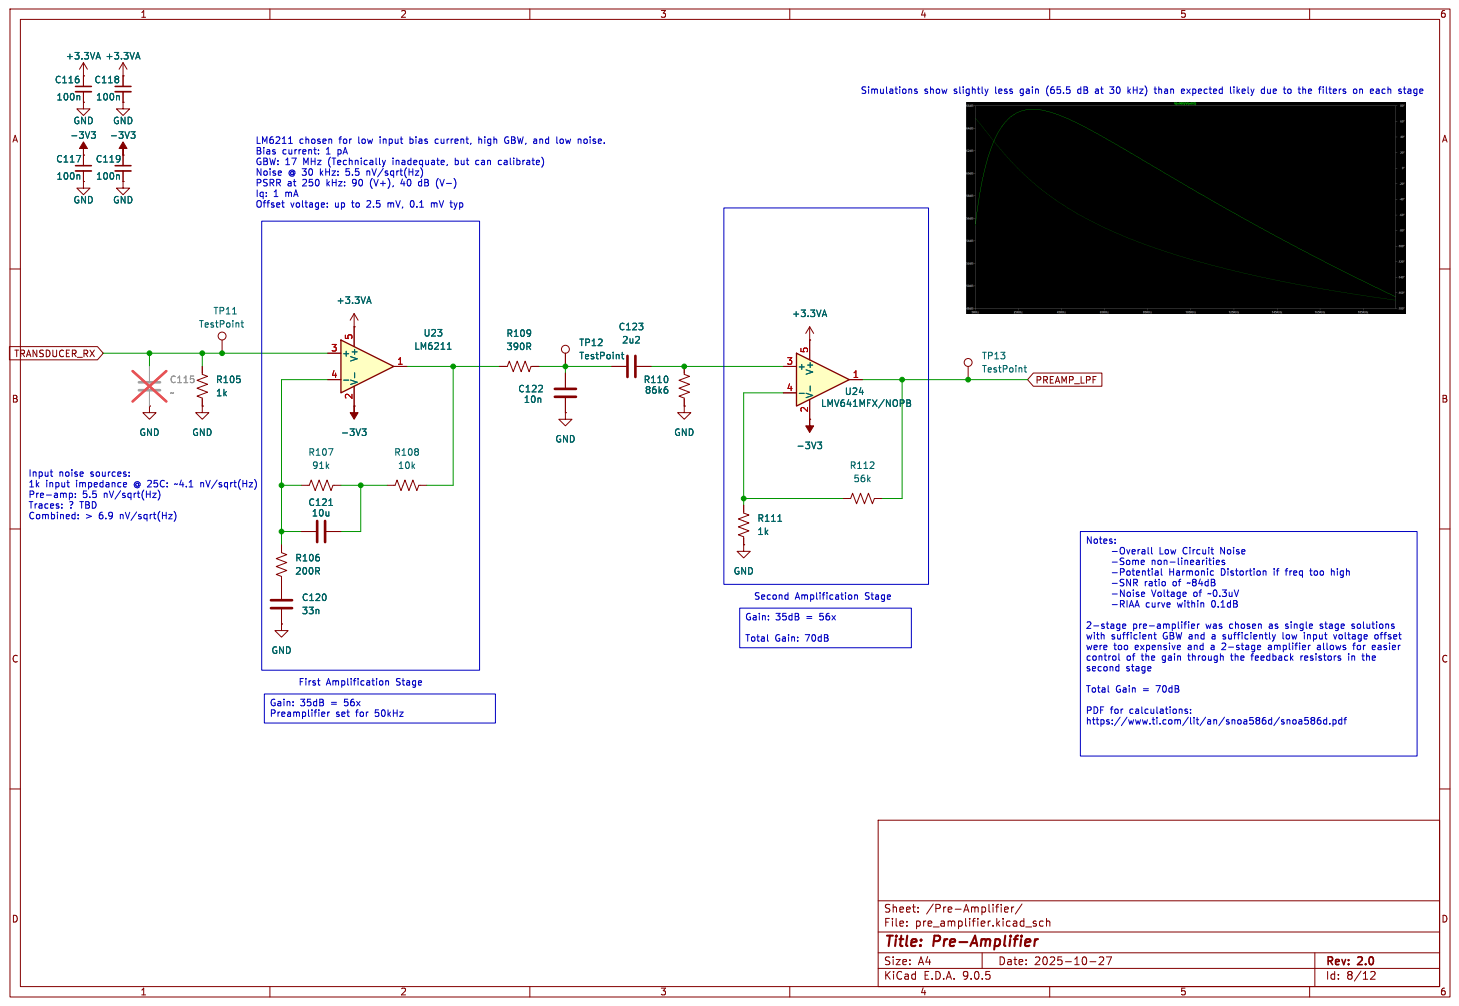
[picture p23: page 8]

Iq: 1 mA Offset voltage: up to 2.5 mV, 0.1 mV typ

Combined: > 6.9 nV/sqrt(Hz)

second stage Total Gain = 70dB

Id: 8/12 Title: Pre-Amplifier File: pre_amplifier.kicad_sch Sheet: /Pre-Amplifier/

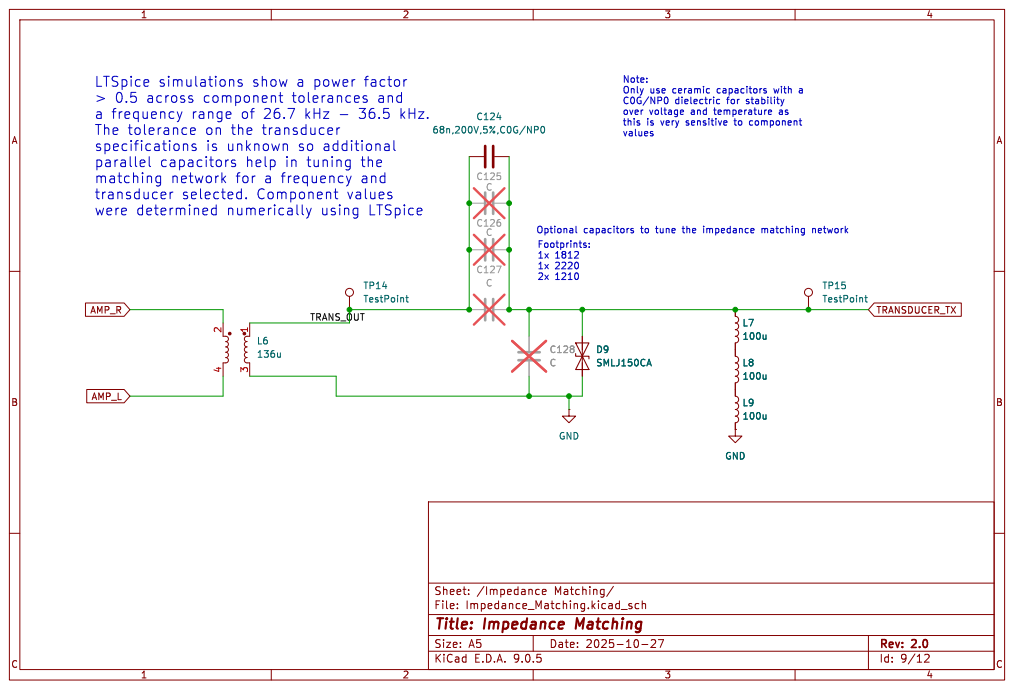
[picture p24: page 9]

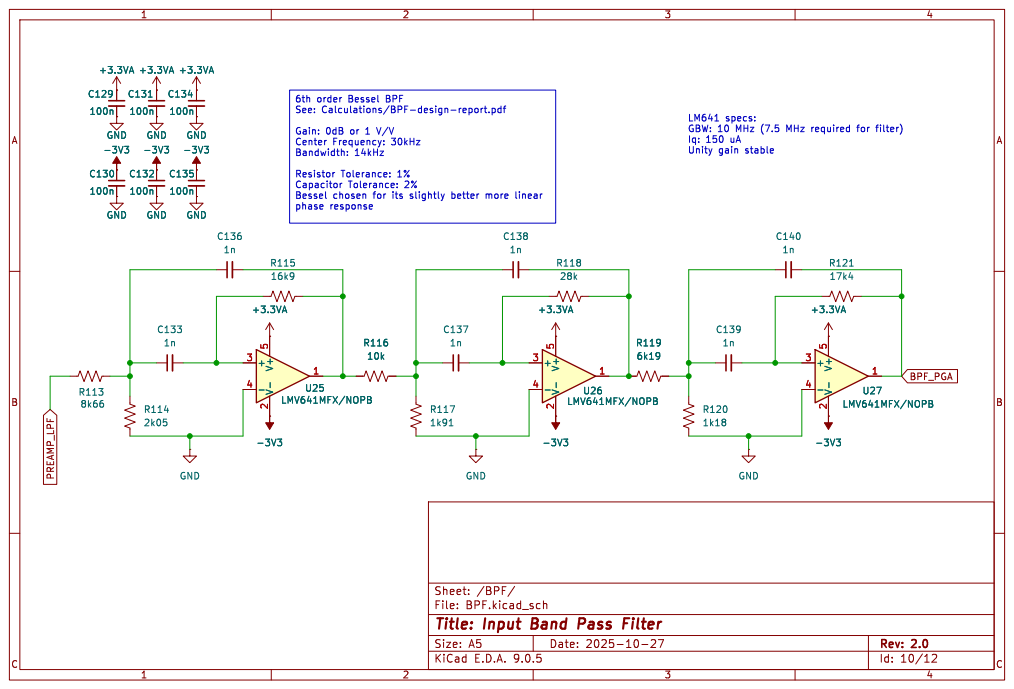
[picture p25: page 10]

See: Calculations/BPF-design-report.pdf

Sheet: /BPF/
Title: Input Band Pass Filter

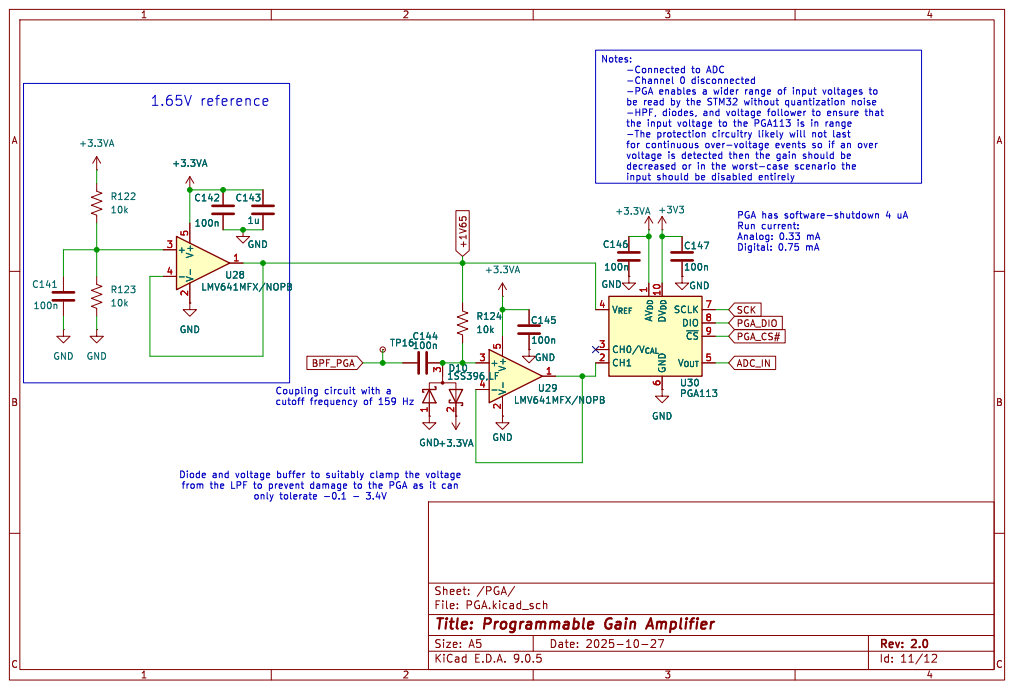
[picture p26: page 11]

from the LPF to prevent damage to the PGA as it can

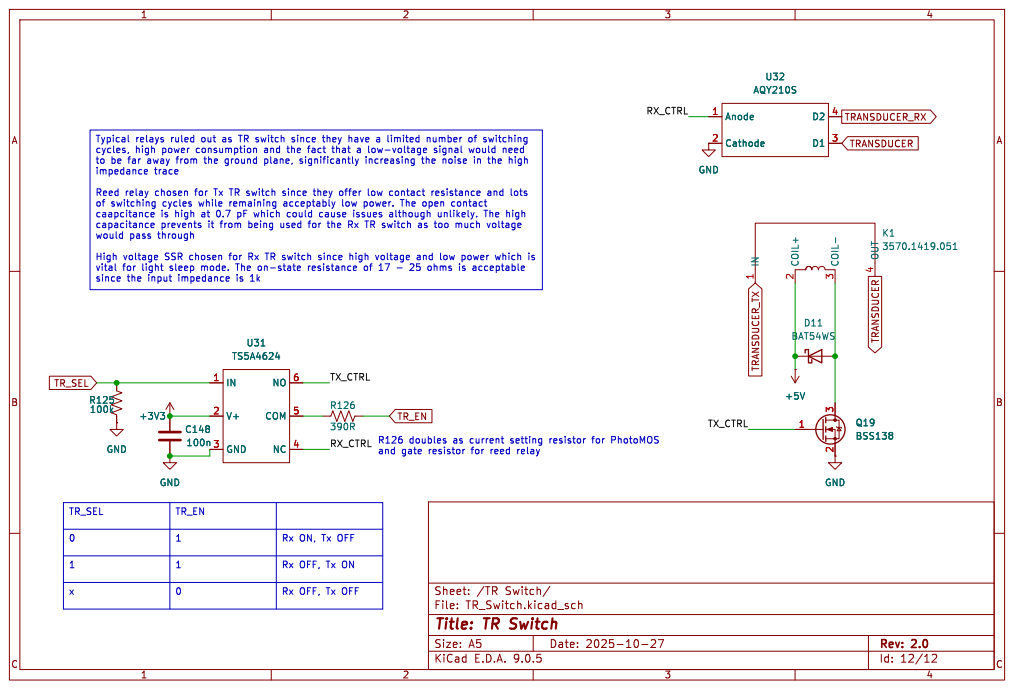
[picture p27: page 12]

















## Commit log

2025-08-19 Start of version 2
    [Connections.kicad_sch, DC-DC.kicad_sch, Feedback.kicad_sch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]
2025-10-16 Most v2 changes made
    [Connections.kicad_sch, DC-DC.kicad_sch, Feedback.kicad_sch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]
2025-10-28 v2 schematics
    [BPF.kicad_sch, Board_Management.kicad_sch, Connections.kicad_sch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]
2026-03-23 v2.0 final version including minor hardware revisions
    [10118193-0001lfc.step, 14-VQFN.STEP, 2601-1102.stp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]

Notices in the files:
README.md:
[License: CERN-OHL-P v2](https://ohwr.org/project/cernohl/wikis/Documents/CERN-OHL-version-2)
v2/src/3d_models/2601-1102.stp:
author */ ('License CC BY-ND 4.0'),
